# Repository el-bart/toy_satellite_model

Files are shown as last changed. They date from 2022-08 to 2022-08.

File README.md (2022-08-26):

# toy satellite model

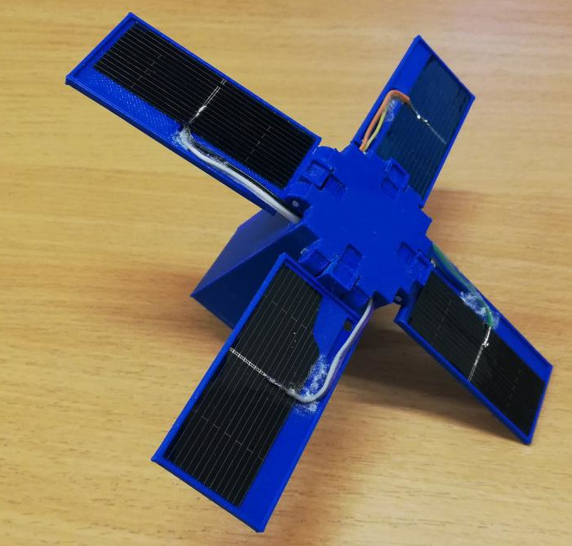
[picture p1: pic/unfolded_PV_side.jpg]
unfolded - PV side

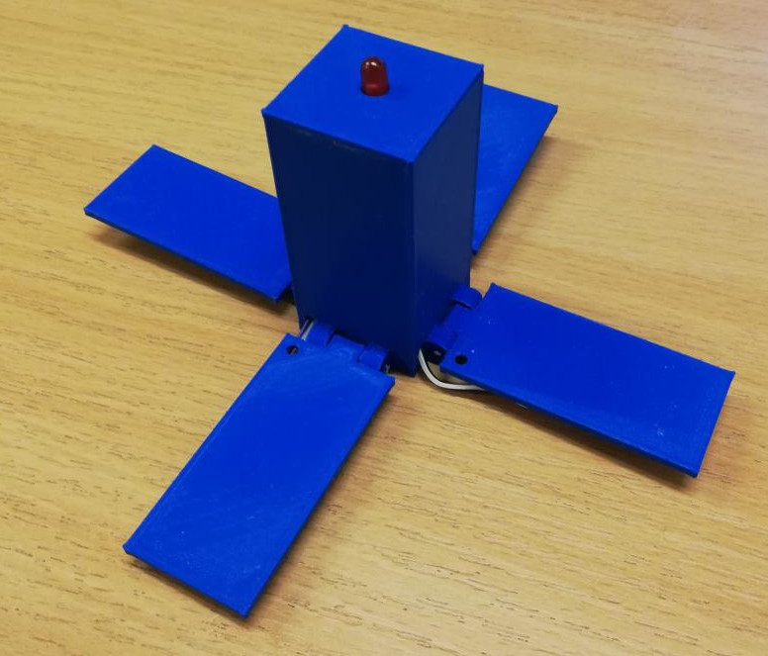
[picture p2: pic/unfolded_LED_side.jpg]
unfolded - LED side


solar-powered toy for children.
when solar panels (PVs) are unfolded, it transmits a message configured in `main.cpp`, using [morse code](https://en.wikipedia.org/wiki/Morse_code).
currently the message is "hello humans of the planet earth". :)
message repeats as long as there is power.

PV panels are foldable.
it is possible to hold them in place with 5x5x1mm neodymium magnets.
in practice however friction-fit of a print is enough.

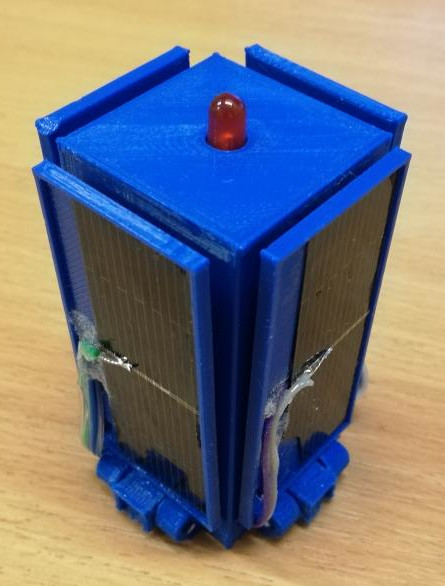
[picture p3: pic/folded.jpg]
folded


## rocket mount

model has been created to fit cargo bay of the [Ariane 5 model](https://github.com/el-bart/external_3d_prints/tree/master/Ariane_5).

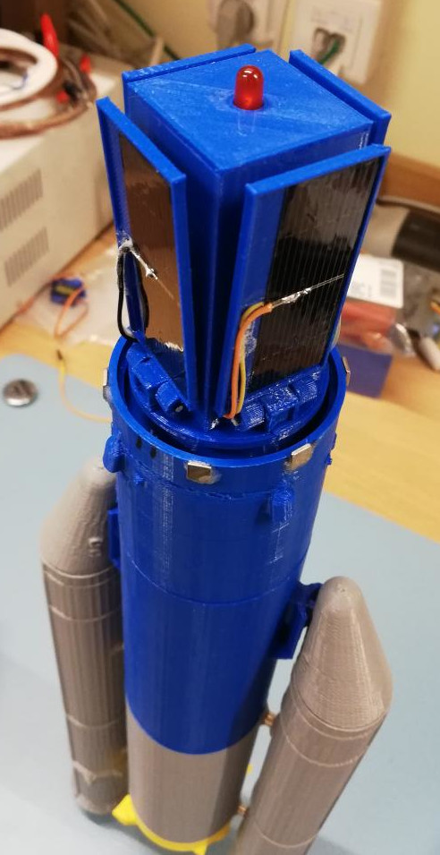
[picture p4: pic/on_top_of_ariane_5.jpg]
on top of Ariane 5 mode


## repo tour

repository consists of 3 main elements:
* `enc/` - 3D printable satellite enclosure (OpenSCAD).
* `sw/` - software for handling LED-blinking in morse code (C++).
* `hw/` - hardware schematic and PCB (KiCad).

all toolchains are dockerized and fully automated.
on linux machine with `docker` it is enough to type `make` in a root directory and all required things will get built for you. :)

## what's needed?

for enclosure you'll obviously need a 3D printer.
it is also possible the order the prints from a factory.
there are no special requirements or print settings
note that hinges for PVs are created using cut line segments of 1.75mm filament, rolled through PV and main body of satellite.

PCB is fairly simple.
you can either order it from your favorite PCB provider or do at home.
even though it's SMD, it deliberately uses large elements, with lots of spacing, to make hand-soldering simple.

in order to flash firmware to microcontroller you'll need a ISP programmer for ATtiny13.
[USBasp](https://www.fischl.de/usbasp/) programmer will do.
just make sure it [supports SCK to program AVR running with a slow clock](https://baszerr.eu/doku.php?id=blog:2022:08:09:2022-08-09_-_slowly_programming_slow_avrs).
note that for ATtiny13 you'll need a programming clamp, as there is no dedicated programming header.

PVs shall be glued to the surface of a PV mount with CA glue.
for the sake of usage it's highly recommended to paint the upper surface with transparent nail paint.
this will further protect panel from damages.
in case it shreds to pieces, it will also prevent small and sharp parts from landing all around the floor.

## version history

### dev
* gerber files are now generated in both `*.tar.gz` and `*.zip` formats
* added help messages for KiCad generator tools
* added BOM generator for PCB
* cable slot on PV panel changed to fit actual cable route.

### v1.1
* PCB holes for PV soldering are now using standard goldpin pitch.
* added some basic documentation.

### v1.0
* fist version even build.
* LED blinking.
* morse code supporting full alphabet.
* fully-automated build (enclosure, software and gerber files for PCB manufacturing).

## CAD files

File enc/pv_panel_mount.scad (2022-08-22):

include <detail/config.scad>


module pv_panel_mock()
{
  // main body
  cube(pv_size);
  // +/- cables
  for(dz=[ pv_size[2], -1 ])
    translate([pv_size[0]/2 - 1/2, 3, dz])
      cube([1, pv_size[1], 1]);
}


module pv_panel_mount()
{
  module pv_holder()
  {
    pv_pos_h = pv_mount_size[2]-pv_size[2]-0.5;
    difference()
    {
      cube(pv_mount_size);
      // panel cut-in
      translate([1, 1, pv_pos_h])
        cube(pv_mount_size - 2*pv_wall_side*[1,1,0]);
      // bottom cable cut-in
      translate([pv_size[0]/2 +1/2, pv_wall_side+pv_spacing, pv_pos_h-1])
        cube([3, pv_size[1]+pv_cable_space, 1+5]);
      // cables slot
      translate([-eps, pv_size[1]+3, pv_pos_h-1])
        cube([pv_size[0]/2 + pv_wall_side, 3, 1+eps]);
    }
    translate([1, 1, pv_pos_h] + pv_spacing*[1,1,0])
      %pv_panel_mock();
  }

  translate([pv_mount_block_size[0], 0, 0])
    pv_holder();
  // side-foot of panel holder
  module block(size)
  {
    x = size[0];
    y = size[1];
    z = size[2];
    r = x/2;
    translate([0, 0, r])
      cube([x,y,z-r]);
    translate([r, 0, 0])
      cube([r, y, r]);
    translate([r, 0, r])
      rotate([-90, 0, 0])
        cylinder(r=r, h=y, $fn=60);
  }
  block_size = pv_mount_block_size;
  translate([0, pv_mount_size[1]/2-block_size[1]/2, 0])
    difference()
    {
      block(block_size);
      // roller
      translate(block_size[0]/2*[1,0,1] - eps*[0,1,0])
        rotate([-90, 0, 0])
          cylinder(d=1.75+0.5, h=pv_mount_size[1]+2*eps, $fn=50);
      // top cut for a magnet
      translate([0, block_size[1]/2-magnet_slot_size[0]/2, block_size[2]-magnet_size[2]])
        translate(magnet_slot_size[0]*[1, 0, 0])
          rotate([0,0, 90])
            cube(magnet_slot_size);
    }
}

for(i=[0:3])
  translate([0, i*(pv_mount_size[1]+2), 0])
    pv_panel_mount();

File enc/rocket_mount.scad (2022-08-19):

include <detail/config.scad>


module rocket_mount()
{
  base_h = 2.5;

  module magnet_slots()
  {
    dr = ( main_block_size[0] - magnet_slot_size[0] )/2;
    for(rot=[0, 90])
      rotate([0, 0, rot])
        for(dx=[-1,1])
          translate([dx*dr, 0, 0])
            translate([0, 0, magnet_slot_size[2]/2 + eps])
              cube(magnet_slot_size, center=true);
  }

  module supports()
  {
    d_ext = pv_mount_block_size[0]/2;
    h = (pv_mount_block_size[2]-3) - (d_ext) - 0.2;
    support_block_size = pv_mount_block_size[2]*[1,1,0] + [0, 0, h];
    dr = ( main_block_size[0] + support_block_size[0] ) / 2 + 0.5;
    for(rot=[0, 90])
      rotate([0, 0, rot])
        for(dx=[-1,1])
          translate([dx*dr, 0, base_h])
            translate([0, 0, support_block_size[2]/2])
              cube(support_block_size, center=true);
  }
  
  module base()
  {
    cylinder(d=45.5, h=base_h, $fn=200);
  }
  
  difference()
  {
    union()
    {
      supports();
      base();
    }
    translate([0, 0, base_h-magnet_slot_size[2]])
      magnet_slots();
  }
}


rocket_mount();

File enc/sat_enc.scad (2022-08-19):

include <detail/config.scad>
use <top_cap.scad>
use <pv_panel_mount.scad>
use <rocket_mount.scad>


module pcb_mock()
{
  rotate([0, -90, 0])
    translate([-94.5,93.8,0])
      import("build/pcb.stl");
}


module main_block()
{
  module pv_harness()
  {
    d_int = 1.75 + 0.5;
    d_ext = pv_mount_block_size[0];
    block_size = [main_block_size[0]/2 + pv_mount_block_size[0]/2, 0, pv_mount_block_size[2]/2];
    l = 5;
    module one_block()
    {
      translate([0, -l/2, 0])
        rotate([-90, 0, 0])
          cylinder(d=d_ext, h=l, $fn=50);
      int_block_size = [d_ext/2, l, pv_mount_block_size[2]];
      translate([-int_block_size[0], -int_block_size[1]/2, -int_block_size[2]/2-1/2])
        cube(int_block_size);
    }
    translate([main_block_size[0]/2 + pv_mount_block_size[0]/2, 0, pv_mount_block_size[2]-3])
      difference()
      {
        for(dy=[-1,1])
          translate([0, dy*(l + pv_mount_block_size[1] + 2*0.5)/2, 0])
            one_block();
        translate((pv_mount_size[1]+2*eps)/2*[0,1,0])
          rotate([90, 0, 0])
            cylinder(d=d_int, h=pv_mount_size[1], $fn=50);
      }
  }

  difference()
  {
    union()
    {
      translate([0, 0, main_block_size[2]/2])
        cube(main_block_size, center=true);
      for(dr=[0:3])
        rotate(dr*[0,0,90])
        {
          pv_harness();
          translate([0, 0, -6])
            %translate([main_block_size[0]/2, pv_mount_size[1]/2, pv_mount_block_size[2]])
              rotate([0, -90, 0])
                rotate([180, 0, 0])
                  pv_panel_mount();
        }
    }
    translate([0, 0, main_block_size[2]/2])
      translate((main_wall+magnet_slot_size[2]+1)*[0,0,1])
        cube(main_block_size - 2*main_wall*[1,1,0], center=true);
    // magnet holes
    mag_offset = main_block_size[0]/2;
    translate([0,0,-eps])
      for(rot=[0,90])
        for(dx=[-1,1])
          rotate([0, 0, rot])
            translate([0, dx*mag_offset, 0])
              rotate([0, 0, (1-dx)*90])
                translate(-magnet_slot_size[0]/2 *[1,2,0])
                  cube(magnet_slot_size);
    // cable holes
    for(dr=[0:3])
      rotate(dr*[0,0,90])
        translate([main_block_size[0]/2, -main_block_size[1]/2+4, 4*main_wall])
          translate([-2*main_wall,0,0])
            rotate([0, 90, 0])
              cylinder(d=3.5, h=main_wall*3, $fn=20);
  }

  %translate([13, -20/2+2, 3*main_wall+4])
    pcb_mock();
}


main_block();

%translate([0,0,63.3+10])
  rotate([180, 0, 0])
    top_cap();

%translate([0, 0, -10])
  rocket_mount();

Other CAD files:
enc/top_cap.scad
enc/detail/config.scad
enc/m3d/fn.scad
enc/m3d/inner_shell.scad
enc/m3d/outer_shell.scad
enc/m3d/rounded_cube.scad
enc/m3d/screw_head_hex.scad

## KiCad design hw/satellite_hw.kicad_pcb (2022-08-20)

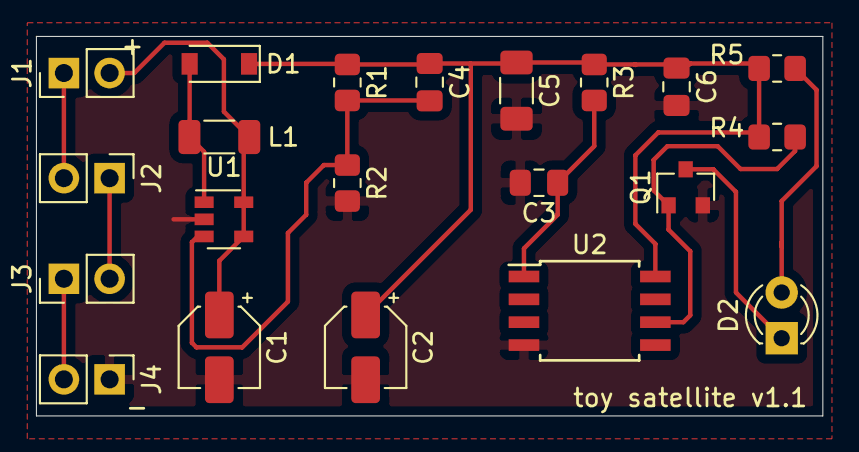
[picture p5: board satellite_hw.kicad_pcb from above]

Board: 2 copper layers, 43.7 x 21.1 mm, 21 parts (0 on the bottom side), 12 nets.

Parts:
C1: 4.7µF; CP_Elec_4x3.9
C2: 20µF; CP_Elec_4x3.9
C3: 4.7nF; C_0805_2012Metric_Pad1.18x1.45mm_HandSolder
C4: 10pF; C_0805_2012Metric_Pad1.18x1.45mm_HandSolder
C5: 100nF; C_1206_3216Metric_Pad1.33x1.80mm_HandSolder
C6: 10nF; C_0805_2012Metric_Pad1.18x1.45mm_HandSolder
D1: D_Schottky; D_SOD-123
D2: red; LED_D3.0mm
J1: solar 1; PinHeader_1x02_P2.54mm_Vertical
J2: solar 2; PinHeader_1x02_P2.54mm_Vertical
J3: solar 3; PinHeader_1x02_P2.54mm_Vertical
J4: solar 4; PinHeader_1x02_P2.54mm_Vertical
L1: 10µH; L_1206_3216Metric_Pad1.22x1.90mm_HandSolder
Q1: 2N7002; SOT-23
R1: 680k; R_0805_2012Metric_Pad1.20x1.40mm_HandSolder
R2: 220k; R_0805_2012Metric_Pad1.20x1.40mm_HandSolder
R3, R4: 10k; R_0805_2012Metric_Pad1.20x1.40mm_HandSolder
R5: 470R; R_0805_2012Metric_Pad1.20x1.40mm_HandSolder
U1: AP3015; SOT-23-5
U2: ATtiny13-20SU; SOIJ-8_5.3x5.3mm_P1.27mm

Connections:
+5V: C2.1, C4.1, C5.1, C6.1, D1.1, R1.1, R3.1, R4.1, R5.1, U2.8
GNDD: C1.2, C2.2, C3.2, C5.2, C6.2, J4.1, Q1.2, R2.2, U1.2, U2.4
unnamed: C3.1, R3.2, U2.1
unnamed: C4.2, R1.2, R2.1, U1.3
unnamed: D1.2, L1.2, U1.1
unnamed: D2.1, Q1.3
unnamed: D2.2, R5.2
unnamed: J1.1, J2.2
unnamed: J2.1, J3.2
unnamed: J3.1, J4.2
unnamed: Q1.1, R4.2, U2.6
VCC: C1.1, J1.2, L1.1, U1.4, U1.5

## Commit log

2022-07-20 empty KiCad project
    [satellite_hw.kicad_pcb, satellite_hw.sch]
2022-07-20 added schematics for AP3015 step-up DC/DC coverter
2022-07-20 DC/DC put onto schematics
    [satellite_hw.sch]
2022-07-20 updated pin negation to be better visible
2022-07-20 ingoring KiCad library backup files, too
2022-07-20 fixed values of elements to make proper DC/DC output + changed transistor for controlling LED
    [satellite_hw.sch]
2022-07-20 draft of elements layout
    [satellite_hw.kicad_pcb]
2022-07-21 added solar panel soldering points
    [satellite_hw.sch]
2022-07-21 PCB elements alignment + board ground layers
    [satellite_hw.kicad_pcb]
2022-07-21 removed bottom layer
    [satellite_hw.kicad_pcb]
2022-07-22 fixed holdpin size
    [satellite_hw.kicad_pcb, satellite_hw.sch]
2022-07-22 fixed THT LED size and pins
    [satellite_hw.kicad_pcb, satellite_hw.sch]
2022-07-22 re-arranging labels on the board
    [satellite_hw.kicad_pcb]
2022-07-22 ignoring generated gerber files
2022-07-22 refilled GND fill on top layer
    [satellite_hw.kicad_pcb]
2022-07-24 build for enclosure
    [fn.scad, inner_shell.scad, outer_shell.scad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]
2022-07-24 tools to make STL from KiCad's PCB
2022-07-24 ingoring generated elements from KiCad
2022-07-24 PCB imported
    [sat_enc.scad]
2022-07-25 KiCad model generator scripts moved to 'hw' section
2022-07-26 added script to generate gerber files
2022-07-26 added rule to generate gerber files
2022-07-26 added more structured dir variables + deps for gerber + full md5sum output in version.txt
2022-07-26 added generation of compressed gerber archive
2022-07-26 added explicit printout for the step
2022-07-26 all zones refilled
    [satellite_hw.kicad_pcb]
2022-07-26 added drill file to generated gerber bundle
2022-07-26 turns out KiCad requires some config template to even start in cmdline mode
2022-07-26 added 'stl' rule to build 3D model
2022-07-26 removed comment on drill files, that are already addressed
2022-07-26 kicad2step is now less verbose
2022-07-26 added extra rule to copy pcb.stl to enclosue's build
2022-07-26 fixed path to pcb.stl (now in generated dirs, where it belongs)
    [sat_enc.scad]
2022-07-26 added main satelite body part
    [sat_enc.scad]
2022-07-26 WIP on solar panel mount
    [sat_enc.scad]
2022-07-27 added properly rounded mount for hinge in the center
    [sat_enc.scad]
2022-07-27 added cable-exit hole at the end of cable corridor
    [sat_enc.scad]
2022-08-07 schematic elements rearanged slighthly, to improve readability
    [satellite_hw.sch]
2022-08-07 skeleton of the program - just blinking LED atm
2022-08-07 disabled fuse bits programming - there's sth off with it, and i have the very last µC on the shelve...
2022-08-07 switched default F_CPU to 9.6MHz (default for internal RC oscillator)
2022-08-09 switched for inlining, as it resulted in smaller program, for a given text
2022-08-17 decreased height of side-foot panel holder
    [sat_enc.scad]
2022-08-17 properly aligned magnets on PV panels holders + magnets on bottom of main satelite body
    [sat_enc.scad]
2022-08-17 removed hardcode from pv_panel_mount() centering routine
    [sat_enc.scad]
2022-08-17 moved whole structure to the center of coordinates
    [sat_enc.scad]
2022-08-17 added more space for PV mount and mount block, so that it can roll easier on the final setup
    [sat_enc.scad]
2022-08-17 added side pv_harness(), consisting of 2 blocks
    [sat_enc.scad]
2022-08-17 added 4x PV panels harnesses + visualization
    [sat_enc.scad]
2022-08-17 moved PCB mock to main_block()'s interior
    [sat_enc.scad]
2022-08-17 PCB moved a bit aside
    [sat_enc.scad]
2022-08-17 TODOs added
    [sat_enc.scad]
2022-08-17 added top_cap() model
    [sat_enc.scad]
2022-08-17 moved config to a separate file
    [config.scad, sat_enc.scad]
2022-08-17 top_cap() moved to a seprate file
    [sat_enc.scad, top_cap.scad]
2022-08-17 PV panel moved to a separate file
    [pv_panel_mount.scad, sat_enc.scad]
2022-08-17 added 4x panels for printing
    [pv_panel_mount.scad]
2022-08-17 added cable holes for PV panels
    [sat_enc.scad]
2022-08-19 removed outdated TODO
    [sat_enc.scad]
2022-08-19 added model of a rocket_mount()
    [rocket_mount.scad]
2022-08-19 added rocket_mount() to main model + fixed formatting in one place + removed solved TODO
    [sat_enc.scad]
2022-08-19 minimized size of rocket_mount()'s base, to make sure it fits into the Ariane 5 model's cargo bay
    [rocket_mount.scad]
2022-08-20 fixed pinheaders to math with typical goldpins
    [satellite_hw.kicad_pcb, satellite_hw.sch]
2022-08-22 fixed cable routing
    [pv_panel_mount.scad]
2022-08-22 added BOM generator for PCB
2022-08-22 integrated BOM generatio into main HW build
2022-08-22 added help to all KiCad generators
2022-08-22 added to readme info about KiCad generator tools help
2022-08-27 fixed gerber files creation for both tar and zip
